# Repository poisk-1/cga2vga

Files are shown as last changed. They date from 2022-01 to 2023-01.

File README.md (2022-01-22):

# CGA to VGA converter

Converts RGBI/HSYNC/VSYNC TTL signal at 15 MHz pixel clock and 640 by 200 resolution to standard VGA. Prototyped on [Arty A7-35T](https://digilent.com/reference/programmable-logic/arty-a7/reference-manual?redirect=1). Production on [Cmod A7-15T](https://digilent.com/reference/programmable-logic/cmod-a7/reference-manual) board.

## Build Top.v

    $ sbt run

## Run tests

    $ sbt test

## Vivado design for Cmod A7-15T

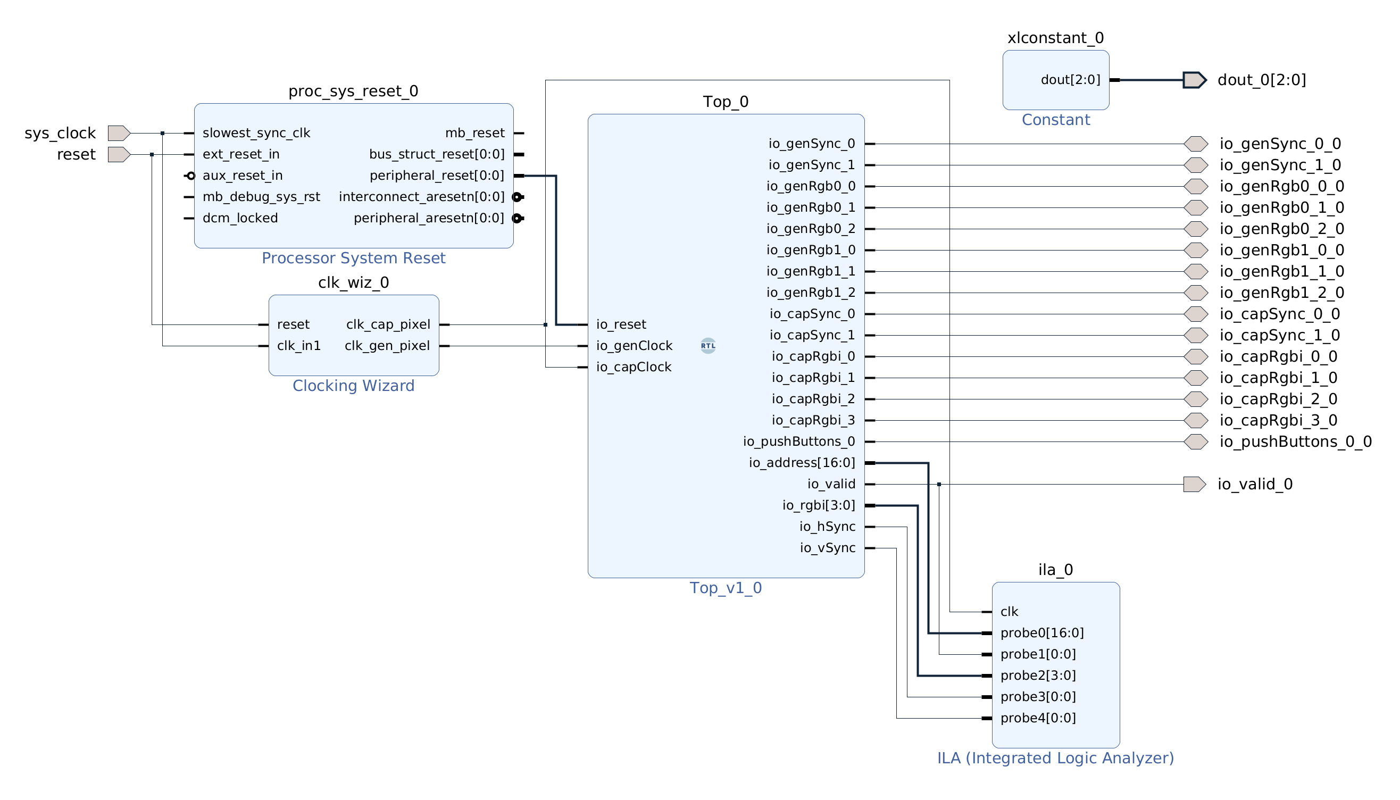
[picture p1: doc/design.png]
Schematics


## TODOs

- Capture alignment configurable with push buttons;
- Design PCB around Cmod A7.

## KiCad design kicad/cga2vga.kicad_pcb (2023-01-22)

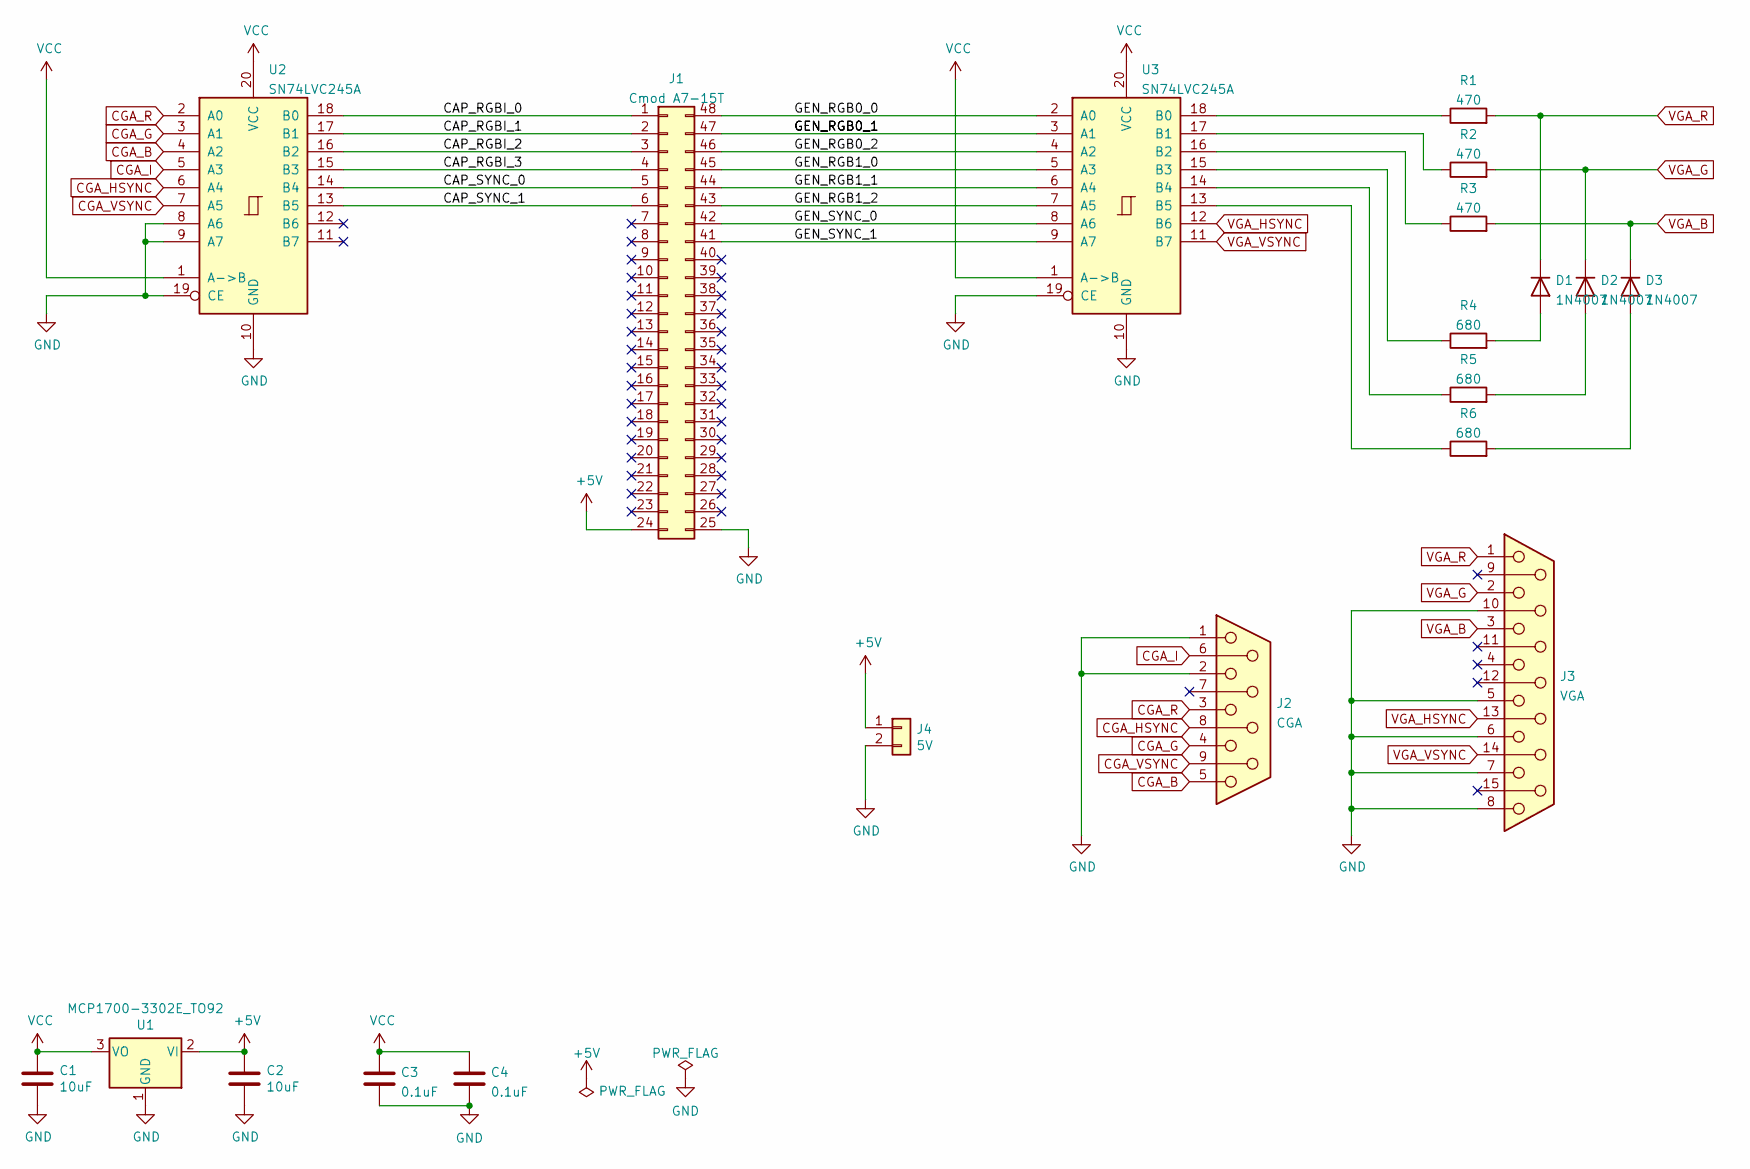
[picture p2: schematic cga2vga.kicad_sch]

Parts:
C1, C2: 10uF; C_Disc_D5.0mm_W2.5mm_P5.00mm
C3, C4: 0.1uF; C_Disc_D3.0mm_W1.6mm_P2.50mm
D1, D2, D3: 1N4007; D_A-405_P7.62mm_Horizontal
J1: Cmod A7-15T; DIP-48_W15.24mm_Socket
J2: CGA; LD09S13A4GX00LF
J3: VGA; L77HDE15SD1CH4F
J4: 5V; SHDR2W66P0X254_1X2_508X572X813P
R1, R2, R3: 470; R_Axial_DIN0207_L6.3mm_D2.5mm_P7.62mm_Horizontal
R4, R5, R6: 680; R_Axial_DIN0207_L6.3mm_D2.5mm_P7.62mm_Horizontal
U1: MCP1700-3302E_TO92; TO-92_HandSolder
U2, U3: SN74LVC245A; DIP-20_W7.62mm_Socket

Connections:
+5V: C2.1, J1.24, J4.1, U1.2 (VI)
/CAP_RGBI_0: J1.1, U2.18 (B0)
/CAP_RGBI_1: J1.2, U2.17 (B1)
/CAP_RGBI_2: J1.3, U2.16 (B2)
/CAP_RGBI_3: J1.4, U2.15 (B3)
/CAP_SYNC_0: J1.5, U2.14 (B4)
/CAP_SYNC_1: J1.6, U2.13 (B5)
/GEN_RGB0_0: J1.48, U3.2 (A0)
/GEN_RGB0_1: J1.47, U3.3 (A1)
/GEN_RGB0_2: J1.46, U3.4 (A2)
/GEN_RGB1_0: J1.45, U3.5 (A3)
/GEN_RGB1_1: J1.44, U3.6 (A4)
/GEN_RGB1_2: J1.43, U3.7 (A5)
/GEN_SYNC_0: J1.42, U3.8 (A6)
/GEN_SYNC_1: J1.41, U3.9 (A7)
CGA_B: J2.5, U2.4 (A2)
CGA_G: J2.4, U2.3 (A1)
CGA_HSYNC: J2.8, U2.6 (A4)
CGA_I: J2.6, U2.5 (A3)
CGA_R: J2.3, U2.2 (A0)
CGA_VSYNC: J2.9, U2.7 (A5)
GND: C1.2, C2.2, C3.2, C4.2, J1.25, J2.1, J2.2, J3.5, J3.6, J3.7, J3.8, J3.10, J4.2, U1.1 (GND), U2.8 (A6), U2.9 (A7), U2.10 (GND), U2.19 (CE), U3.10 (GND), U3.19 (CE)
unnamed: D1.2 (A), R4.2
unnamed: D2.2 (A), R5.2
unnamed: D3.2 (A), R6.2
unnamed: R1.1, U3.18 (B0)
unnamed: R2.1, U3.17 (B1)
unnamed: R3.1, U3.16 (B2)
unnamed: R4.1, U3.15 (B3)
unnamed: R5.1, U3.14 (B4)
unnamed: R6.1, U3.13 (B5)
VCC: C1.1, C3.1, C4.1, U1.3 (VO), U2.1 (A->B), U2.20 (VCC), U3.1 (A->B), U3.20 (VCC)
VGA_B: D3.1 (K), J3.3, R3.2
VGA_G: D2.1 (K), J3.2, R2.2
VGA_HSYNC: J3.13, U3.12 (B6)
VGA_R: D1.1 (K), J3.1, R1.2
VGA_VSYNC: J3.14, U3.11 (B7)

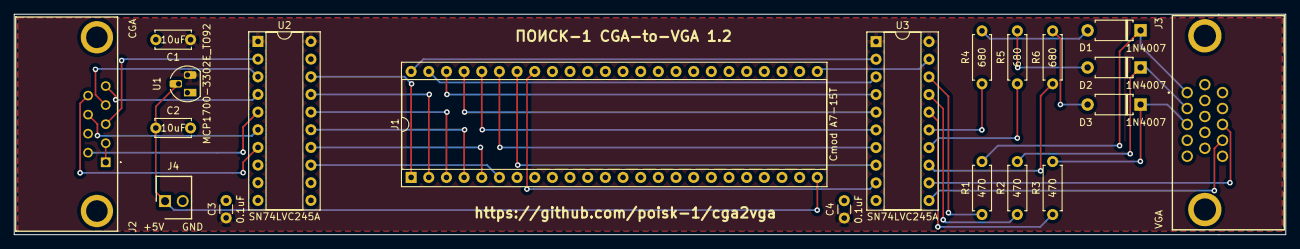
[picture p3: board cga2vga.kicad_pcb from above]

Board: 2 copper layers, 182.9 x 31.7 mm, 20 parts (0 on the bottom side), 37 nets.

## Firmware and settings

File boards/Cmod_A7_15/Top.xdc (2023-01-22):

## This file is a general .xdc for the CmodA7 rev. B
## To use it in a project:
## - uncomment the lines corresponding to used pins
## - rename the used ports (in each line, after get_ports) according to the top level signal names in the project

## 12 MHz Clock Signal
#set_property -dict { PACKAGE_PIN L17   IOSTANDARD LVCMOS33 } [get_ports { sysclk }]; #IO_L12P_T1_MRCC_14 Sch=gclk
#create_clock -add -name sys_clk_pin -period 83.33 -waveform {0 41.66} [get_ports {sysclk}];

## LEDs
set_property -dict {PACKAGE_PIN A17 IOSTANDARD LVCMOS33} [get_ports io_valid_0]
#set_property -dict { PACKAGE_PIN C16   IOSTANDARD LVCMOS33 } [get_ports { led[1] }]; #IO_L13P_T2_MRCC_16 Sch=led[2]

## RGB LED
set_property -dict {PACKAGE_PIN B17 IOSTANDARD LVCMOS33} [get_ports dout_0[0]]
set_property -dict {PACKAGE_PIN B16 IOSTANDARD LVCMOS33} [get_ports dout_0[1]]
set_property -dict {PACKAGE_PIN C17 IOSTANDARD LVCMOS33} [get_ports dout_0[2]]

## Buttons
#set_property -dict { PACKAGE_PIN A18   IOSTANDARD LVCMOS33 } [get_ports { btn[0] }]; #IO_L19N_T3_VREF_16 Sch=btn[0]
set_property -dict {PACKAGE_PIN B18 IOSTANDARD LVCMOS33} [get_ports io_pushButtons_0_0]

## Pmod Header JA
#set_property -dict { PACKAGE_PIN G17   IOSTANDARD LVCMOS33 } [get_ports { ja[0] }]; #IO_L5N_T0_D07_14 Sch=ja[1]
#set_property -dict { PACKAGE_PIN G19   IOSTANDARD LVCMOS33 } [get_ports { ja[1] }]; #IO_L4N_T0_D05_14 Sch=ja[2]
#set_property -dict { PACKAGE_PIN N18   IOSTANDARD LVCMOS33 } [get_ports { ja[2] }]; #IO_L9P_T1_DQS_14 Sch=ja[3]
#set_property -dict { PACKAGE_PIN L18   IOSTANDARD LVCMOS33 } [get_ports { ja[3] }]; #IO_L8P_T1_D11_14 Sch=ja[4]
#set_property -dict { PACKAGE_PIN H17   IOSTANDARD LVCMOS33 } [get_ports { ja[4] }]; #IO_L5P_T0_D06_14 Sch=ja[7]
#set_property -dict { PACKAGE_PIN H19   IOSTANDARD LVCMOS33 } [get_ports { ja[5] }]; #IO_L4P_T0_D04_14 Sch=ja[8]
#set_property -dict { PACKAGE_PIN J19   IOSTANDARD LVCMOS33 } [get_ports { ja[6] }]; #IO_L6N_T0_D08_VREF_14 Sch=ja[9]
#set_property -dict { PACKAGE_PIN K18   IOSTANDARD LVCMOS33 } [get_ports { ja[7] }]; #IO_L8N_T1_D12_14 Sch=ja[10]

## Analog XADC Pins
## Only declare these if you want to use pins 15 and 16 as single ended analog inputs. pin 15 -> vaux4, pin16 -> vaux12
#set_property -dict { PACKAGE_PIN G2    IOSTANDARD LVCMOS33 } [get_ports { xa_n[0] }]; #IO_L1N_T0_AD4N_35 Sch=ain_n[15]
#set_property -dict { PACKAGE_PIN G3    IOSTANDARD LVCMOS33 } [get_ports { xa_p[0] }]; #IO_L1P_T0_AD4P_35 Sch=ain_p[15]
#set_property -dict { PACKAGE_PIN J2    IOSTANDARD LVCMOS33 } [get_ports { xa_n[1] }]; #IO_L2N_T0_AD12N_35 Sch=ain_n[16]
#set_property -dict { PACKAGE_PIN H2    IOSTANDARD LVCMOS33 } [get_ports { xa_p[1] }]; #IO_L2P_T0_AD12P_35 Sch=ain_p[16]
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

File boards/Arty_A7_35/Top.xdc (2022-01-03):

## This file is a general .xdc for the Arty A7-35 Rev. D
## To use it in a project:
## - uncomment the lines corresponding to used pins
## - rename the used ports (in each line, after get_ports) according to the top level signal names in the project

## Clock signal
#set_property -dict { PACKAGE_PIN E3    IOSTANDARD LVCMOS33 } [get_ports { CLK100MHZ }]; #IO_L12P_T1_MRCC_35 Sch=gclk[100]
#create_clock -add -name sys_clk_pin -period 10.00 -waveform {0 5} [get_ports { CLK100MHZ }];

## Switches
#set_property -dict { PACKAGE_PIN A8    IOSTANDARD LVCMOS33 } [get_ports { sw[0] }]; #IO_L12N_T1_MRCC_16 Sch=sw[0]
#set_property -dict { PACKAGE_PIN C11   IOSTANDARD LVCMOS33 } [get_ports { sw[1] }]; #IO_L13P_T2_MRCC_16 Sch=sw[1]
#set_property -dict { PACKAGE_PIN C10   IOSTANDARD LVCMOS33 } [get_ports { sw[2] }]; #IO_L13N_T2_MRCC_16 Sch=sw[2]
#set_property -dict { PACKAGE_PIN A10   IOSTANDARD LVCMOS33 } [get_ports { sw[3] }]; #IO_L14P_T2_SRCC_16 Sch=sw[3]

## RGB LEDs
#set_property -dict { PACKAGE_PIN E1    IOSTANDARD LVCMOS33 } [get_ports { led0_b }]; #IO_L18N_T2_35 Sch=led0_b
#set_property -dict { PACKAGE_PIN F6    IOSTANDARD LVCMOS33 } [get_ports { led0_g }]; #IO_L19N_T3_VREF_35 Sch=led0_g
#set_property -dict { PACKAGE_PIN G6    IOSTANDARD LVCMOS33 } [get_ports { led0_r }]; #IO_L19P_T3_35 Sch=led0_r
#set_property -dict { PACKAGE_PIN G4    IOSTANDARD LVCMOS33 } [get_ports { led1_b }]; #IO_L20P_T3_35 Sch=led1_b
#set_property -dict { PACKAGE_PIN J4    IOSTANDARD LVCMOS33 } [get_ports { led1_g }]; #IO_L21P_T3_DQS_35 Sch=led1_g
#set_property -dict { PACKAGE_PIN G3    IOSTANDARD LVCMOS33 } [get_ports { led1_r }]; #IO_L20N_T3_35 Sch=led1_r
#set_property -dict { PACKAGE_PIN H4    IOSTANDARD LVCMOS33 } [get_ports { led2_b }]; #IO_L21N_T3_DQS_35 Sch=led2_b
#set_property -dict { PACKAGE_PIN J2    IOSTANDARD LVCMOS33 } [get_ports { led2_g }]; #IO_L22N_T3_35 Sch=led2_g
#set_property -dict { PACKAGE_PIN J3    IOSTANDARD LVCMOS33 } [get_ports { led2_r }]; #IO_L22P_T3_35 Sch=led2_r
#set_property -dict { PACKAGE_PIN K2    IOSTANDARD LVCMOS33 } [get_ports { led3_b }]; #IO_L23P_T3_35 Sch=led3_b
#set_property -dict { PACKAGE_PIN H6    IOSTANDARD LVCMOS33 } [get_ports { led3_g }]; #IO_L24P_T3_35 Sch=led3_g
#set_property -dict { PACKAGE_PIN K1    IOSTANDARD LVCMOS33 } [get_ports { led3_r }]; #IO_L23N_T3_35 Sch=led3_r

## LEDs
#set_property -dict { PACKAGE_PIN H5    IOSTANDARD LVCMOS33 } [get_ports { led[0] }]; #IO_L24N_T3_35 Sch=led[4]
#set_property -dict { PACKAGE_PIN J5    IOSTANDARD LVCMOS33 } [get_ports { led[1] }]; #IO_25_35 Sch=led[5]
#set_property -dict { PACKAGE_PIN T9    IOSTANDARD LVCMOS33 } [get_ports { led[2] }]; #IO_L24P_T3_A01_D17_14 Sch=led[6]
#set_property -dict { PACKAGE_PIN T10   IOSTANDARD LVCMOS33 } [get_ports { led[3] }]; #IO_L24N_T3_A00_D16_14 Sch=led[7]

## Buttons
set_property -dict { PACKAGE_PIN D9    IOSTANDARD LVCMOS33 } [get_ports { io_pushButtons_0_0 }]; #IO_L6N_T0_VREF_16 Sch=btn[0]
set_property -dict { PACKAGE_PIN C9    IOSTANDARD LVCMOS33 } [get_ports { io_pushButtons_1_0 }]; #IO_L11P_T1_SRCC_16 Sch=btn[1]
#set_property -dict { PACKAGE_PIN B9    IOSTANDARD LVCMOS33 } [get_ports { io_pushButtons_0[2] }]; #IO_L11N_T1_SRCC_16 Sch=btn[2]
#set_property -dict { PACKAGE_PIN B8    IOSTANDARD LVCMOS33 } [get_ports { io_pushButtons_0[3] }]; #IO_L12P_T1_MRCC_16 Sch=btn[3]

## Pmod Header JA
set_property -dict { PACKAGE_PIN G13   IOSTANDARD LVCMOS33 } [get_ports { io_capSync_0_0 }]; #IO_0_15 Sch=ja[1]
set_property -dict { PACKAGE_PIN B11   IOSTANDARD LVCMOS33 } [get_ports { io_capSync_1_0 }]; #IO_L4P_T0_15 Sch=ja[2]
#set_property -dict { PACKAGE_PIN A11   IOSTANDARD LVCMOS33 } [get_ports { io_capSync_0[2] }]; #IO_L4N_T0_15 Sch=ja[3]
#set_property -dict { PACKAGE_PIN D12   IOSTANDARD LVCMOS33 } [get_ports { io_capSync_0[3] }]; #IO_L6P_T0_15 Sch=ja[4]
set_property -dict { PACKAGE_PIN D13   IOSTANDARD LVCMOS33 } [get_ports { io_capRgbi_0_0 }]; #IO_L6N_T0_VREF_15 Sch=ja[7]
set_property -dict { PACKAGE_PIN B18   IOSTANDARD LVCMOS33 } [get_ports { io_capRgbi_1_0 }]; #IO_L10P_T1_AD11P_15 Sch=ja[8]
set_property -dict { PACKAGE_PIN A18   IOSTANDARD LVCMOS33 } [get_ports { io_capRgbi_2_0 }]; #IO_L10N_T1_AD11N_15 Sch=ja[9]
set_property -dict { PACKAGE_PIN K16   IOSTANDARD LVCMOS33 } [get_ports { io_capRgbi_3_0 }]; #IO_25_15 Sch=ja[10]
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

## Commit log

2021-12-29 Frame buffer
2022-02-02 The PCB
    [cga2vga.kicad_pcb, cga2vga.kicad_sch]
2022-02-02 Fix power connector marking
    [cga2vga.kicad_pcb, cga2vga.kicad_sch]
2022-02-13 Fix color
    [cga2vga.kicad_sch]
2022-02-13 Ground unused inputs
    [cga2vga.kicad_sch]
2022-02-13 Valid LED
2023-01-22 Update PCB
    [cga2vga.kicad_pcb]
